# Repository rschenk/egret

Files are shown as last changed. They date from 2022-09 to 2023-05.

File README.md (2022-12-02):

# Egret

A 36 key Choc-spaced monoblock keyboard that's wireless compatible, hot swappable, gasket mounted, and very thin. Inspired by the [chocV](https://github.com/brickbots/chocV) and [Horizon](https://github.com/skarrmann/horizon/).

The Egret's bottom plate has cutouts for the hotswap sockets, essentially the thinnest board possible with hotswap sockets. Silicone gaskets sandwiching both sides of the PCB dampen sounds and vibrations. The entire bottom is covered with rubber sheet so you can use it right on your laptop keys if you're so inclined!

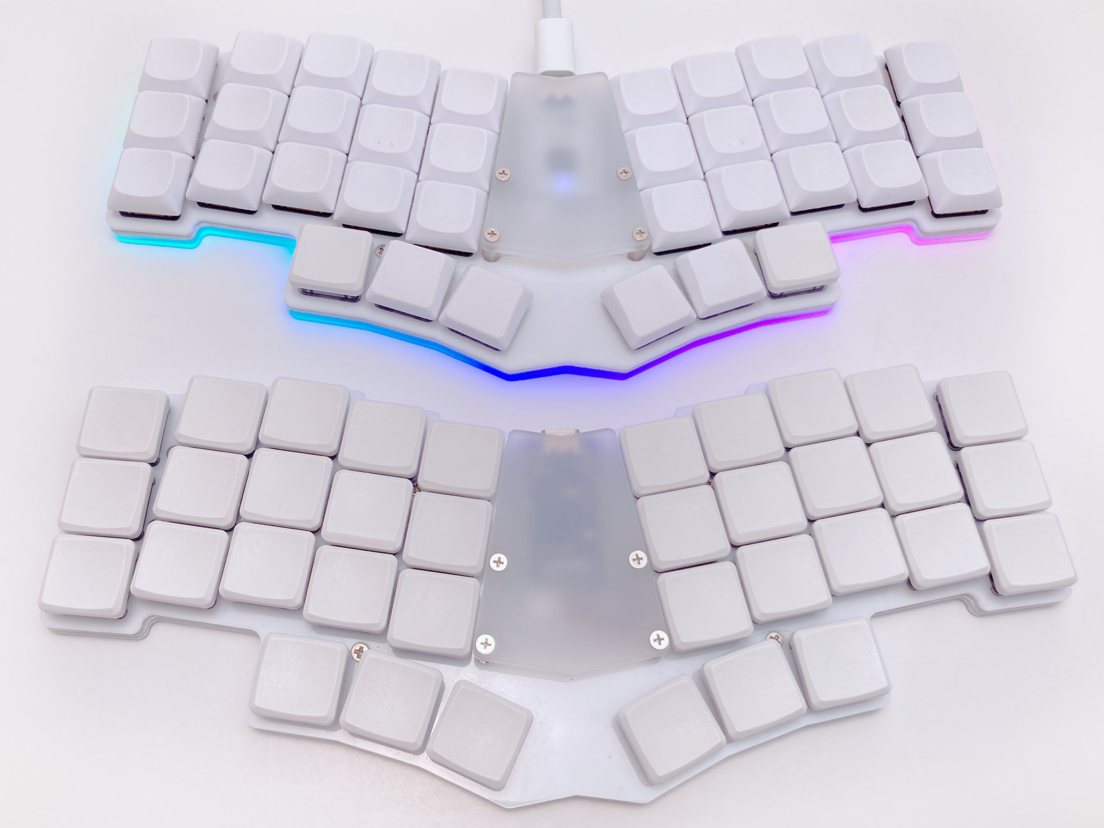
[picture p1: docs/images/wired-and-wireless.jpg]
wired-and-wireless


## Features

* Choc hotswap sockets with Choc spacing
* Gasket mounted
* On/off slider switch and JST plug for battery power
* Totally flat bottom, so you can put it right on top of your laptop keyboard and Miyoku on the go
* Optional LED underglow for wired mode, if underglow is your thing. It's very much my thing
* Two bottom plate options: lowpro mode for the thinnest board physically possible, or glowpro mode for epic underglow at the expense of a couple mm of thickess.

## Wicked Thin and Flat

The bottom plate is cut out to accomodate the hotswap sockets, making it about as thin as is physically possible to make a hotswap board. The entire bottom is intended to be covered with rubber, sililicone, EVA, etc, so you can put it down on right over your laptop's keys. Yes this actually works and is useable! 

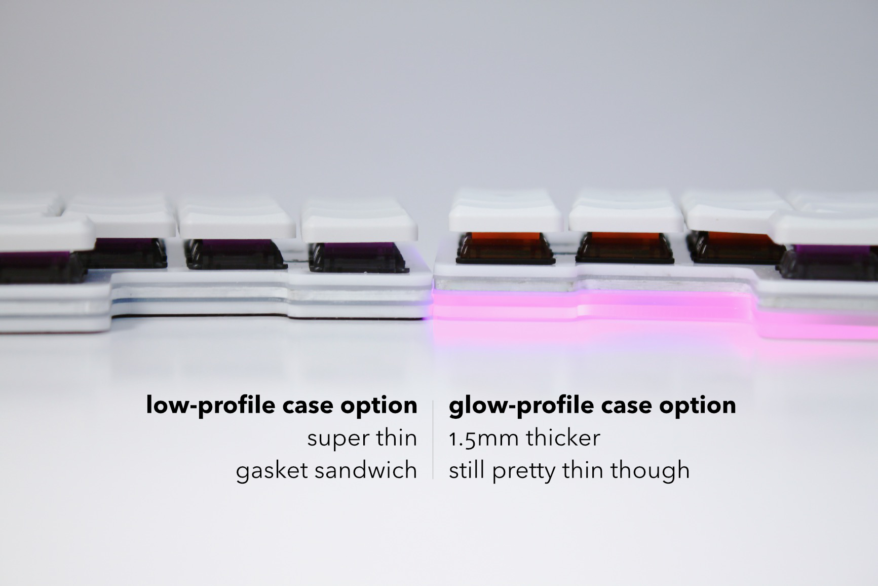
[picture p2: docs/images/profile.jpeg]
profile


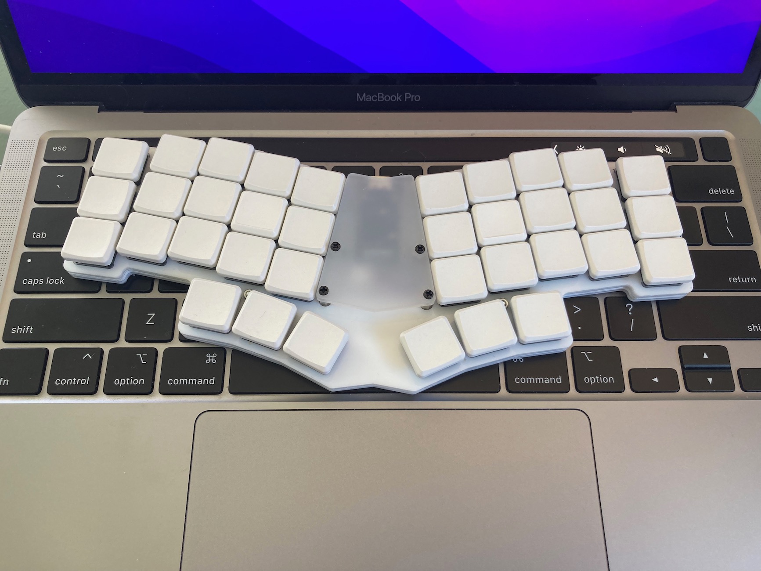
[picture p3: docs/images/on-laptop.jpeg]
on-laptop


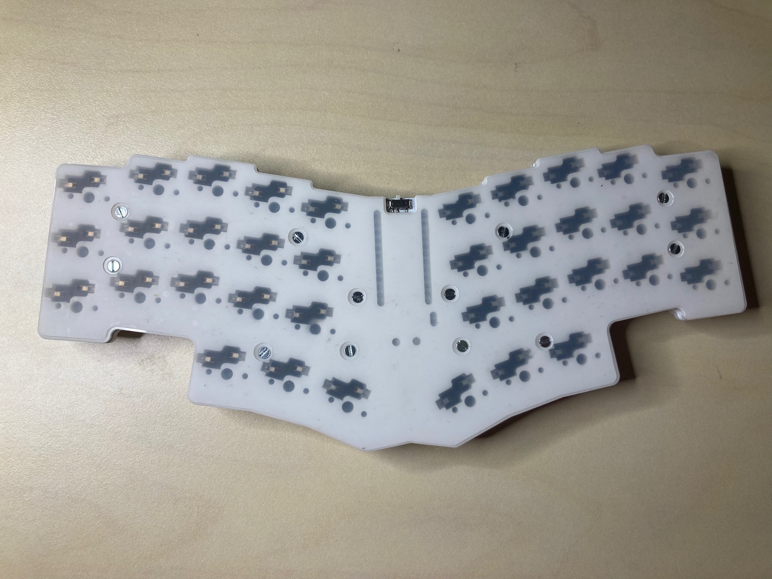
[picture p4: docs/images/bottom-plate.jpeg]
bottom-plate


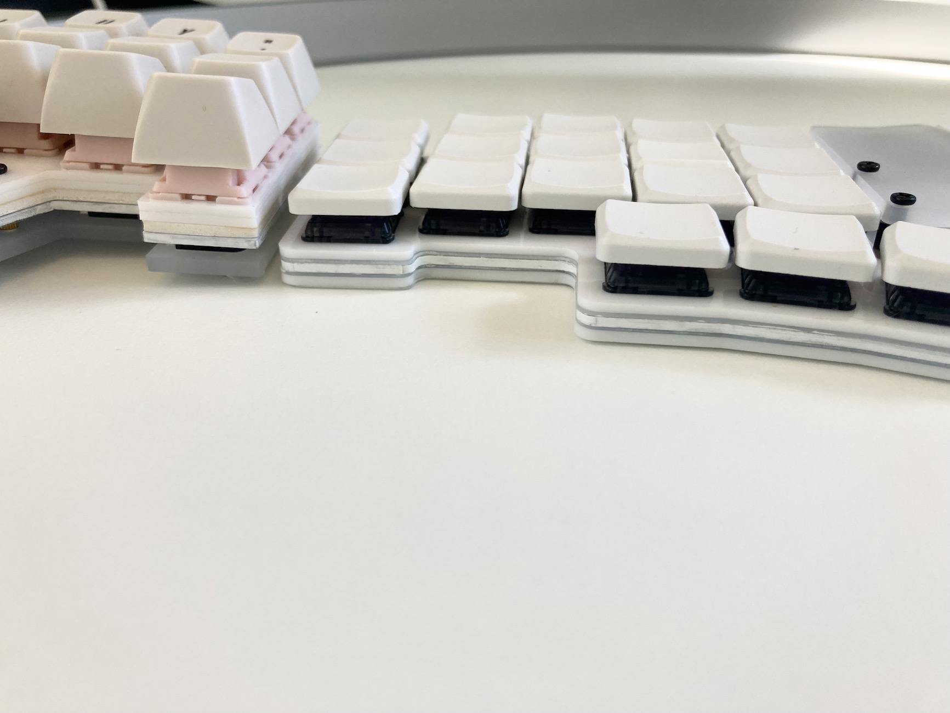
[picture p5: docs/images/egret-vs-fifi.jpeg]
egret-vs-fifi


## Build Guide

There are two ways to build it, with LED underglow (glow-profile case) and without (low profile case). The LED version requires a different bottom plate which is 1.5mm taller than the low-profile version, but everything else is the same between them—same PCB, top plate, gaskets, etc. _Either_ version can be used with bluetooth! Obviously running the LEDs will drain your battery much faster, but it's easy to have  the best of both worlds by configuring ZMK to automatically enable LEDs when plugged into USB and disable them when on battery power.

* Build guide for [low profile version](./docs/rev1/build_guide_lowpro_rev1.md) (no LEDs)
* Build guide for [glow profile version](./docs/rev1/build_guide_glowpro_rev1.md) (with LED underglow)

## Firmware

### QMK

Egret is not in the main QMK repo yet (or probably ever) but it's easy to add to your local.
Assuming you already have QMK set up on your computer, copy the contents of `./firmware/qmk` to `qmk_firmware/keyboards/egret`. There is a very minimal basic keymap for you to start with.

```sh
cp -R ./firmware/qmk /path/to/qmk_firmware/keyboards/egret
cd !$
cp -R keymaps/default keymaps/your-github-username
```

### ZMK

Egret is not in the main ZMK repo but it's easy to add. Assuming you already have a zmk-config setp already, copy the contents of `./firmware/zmk` to `zmk-config/config/boards/shields/egret`, then make the usual setup. There is a basic minimal keymap for you to start with.

```sh
cp -R ./firmware/zmk /path/to/zmk-config/config/boards/shields/egret
cd /path/to/zmk-config/config
cp boards/shields/egret/egret.keymap .
touch egret.conf
```

## Tweak Your Own With Ergogen

This board is generated with the amazing ergogen tool, then post-processed with KiCad and vector graphics drawing tools. I used several custom footrpints to pull off the "horizon construction" on the bottom plate. Since ergogen does not currently support adding footprints at runtime, I Dockerized it and copied my footprints into the image. The Dockerfile lives in `ergogen/container` and can be run with a little wrapper script I wrote in `ergogen/bin/ergogen`. 

To generate the board (which you should not need to unless you want to change something):

```shell
$ cd ergogen
$ bin/ergogen egret.yml
```

If you decide to edit a footprint, you'll need to remove the image and rebuild it.
```shell
# Only if you modify a footprint, rebuild the image like so:
$ docker image rm -f ergogen-egret && bin/ergogen egret.yml
```

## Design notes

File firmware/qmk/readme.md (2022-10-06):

# egret

egret

*A short description of the keyboard/project*

* Keyboard Maintainer: [Ryan Schenk](https://github.com/rschenk)
* Hardware Supported: *The PCBs, controllers supported*
* Hardware Availability: *Links to where you can find this hardware*

Make example for this keyboard (after setting up your build environment):

    make egret:default

Flashing example for this keyboard:

    make egret:default:flash

See the [build environment setup](https://docs.qmk.fm/#/getting_started_build_tools) and the [make instructions](https://docs.qmk.fm/#/getting_started_make_guide) for more information. Brand new to QMK? Start with our [Complete Newbs Guide](https://docs.qmk.fm/#/newbs).

## Bootloader

Enter the bootloader in 3 ways:

* **Bootmagic reset**: Hold down the key at (0,0) in the matrix (usually the top left key or Escape) and plug in the keyboard
* **Physical reset button**: Briefly press the button on the back of the PCB - some may have pads you must short instead
* **Keycode in layout**: Press the key mapped to `QK_BOOT` if it is available

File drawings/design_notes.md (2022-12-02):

PEM M2 fastener hole should be 0.118" (3.00mm) in the drawing to be a perfect fit after lasering.

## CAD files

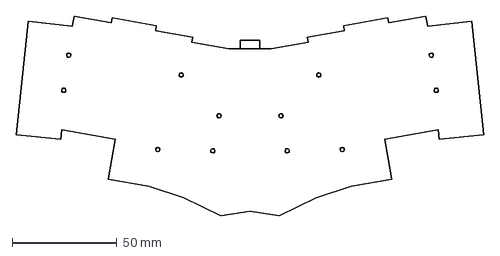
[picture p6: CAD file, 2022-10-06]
ergogen/output/outlines/bottom_plate_glowpro.dxf
223.7 x 95.4 mm

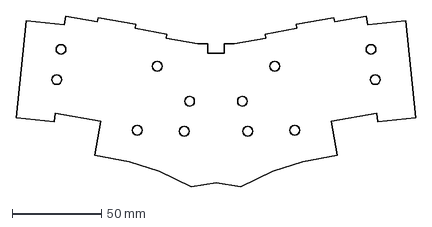
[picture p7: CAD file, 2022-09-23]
ergogen/output/outlines/bottom_grip.dxf
223.7 x 95.4 mm

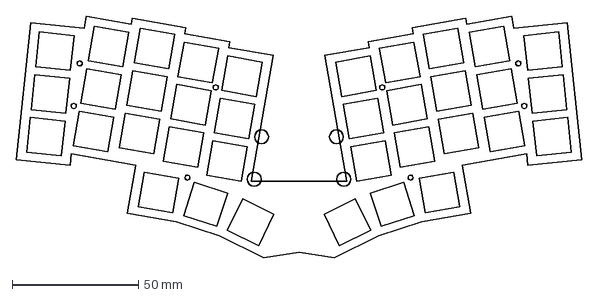
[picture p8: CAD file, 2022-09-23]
ergogen/output/outlines/top_plate.dxf
223.7 x 95.4 mm

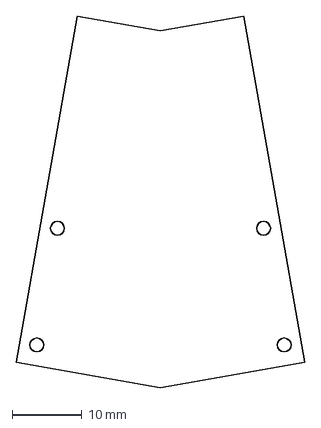
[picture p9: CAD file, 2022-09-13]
ergogen/output/outlines/mcu_cover.dxf
41.5 x 53.4 mm

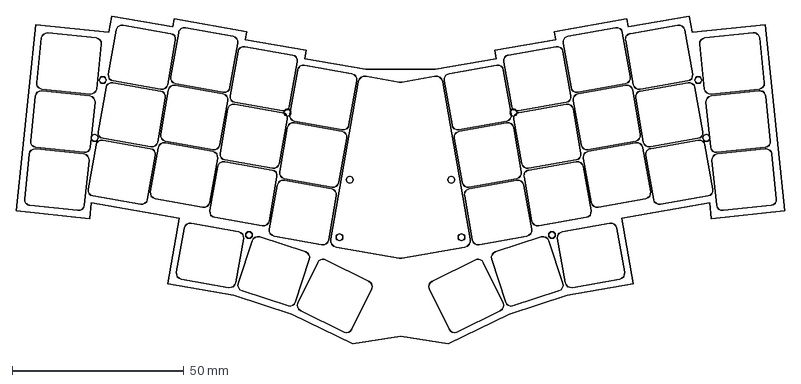
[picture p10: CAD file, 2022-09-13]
ergogen/output/outlines/test.dxf
223.7 x 95.4 mm

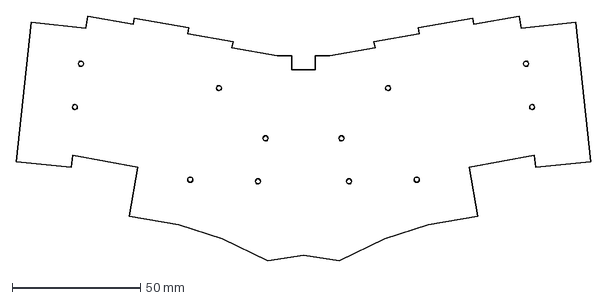
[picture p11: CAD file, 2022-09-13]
ergogen/output/outlines/bottom_plate_lowpro.dxf
223.7 x 95.4 mm

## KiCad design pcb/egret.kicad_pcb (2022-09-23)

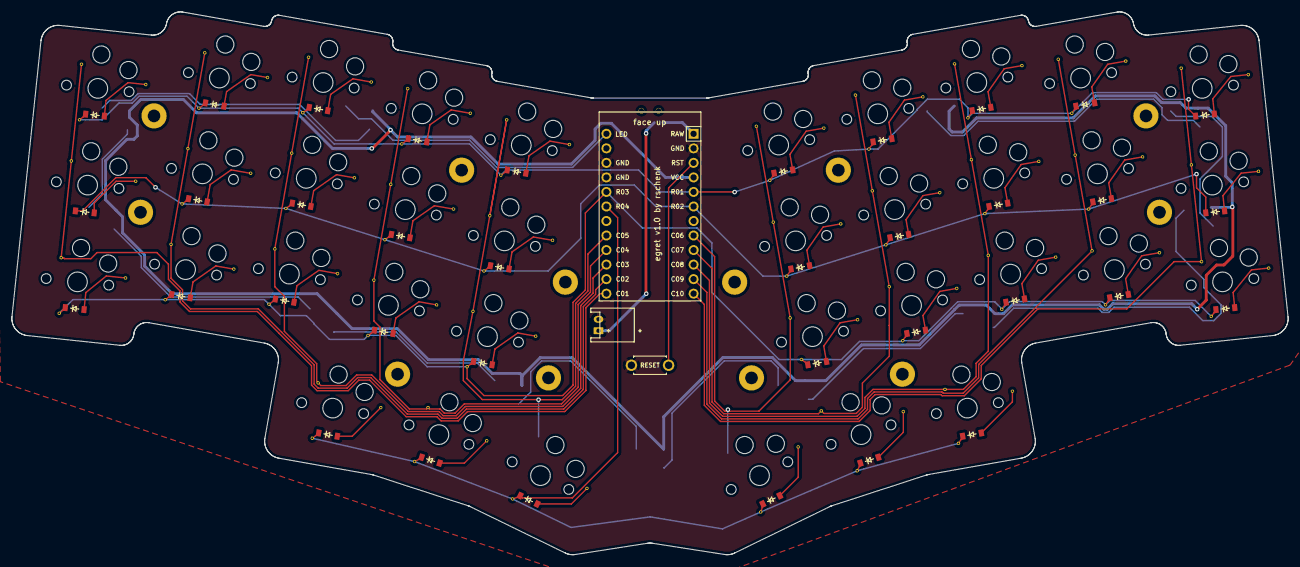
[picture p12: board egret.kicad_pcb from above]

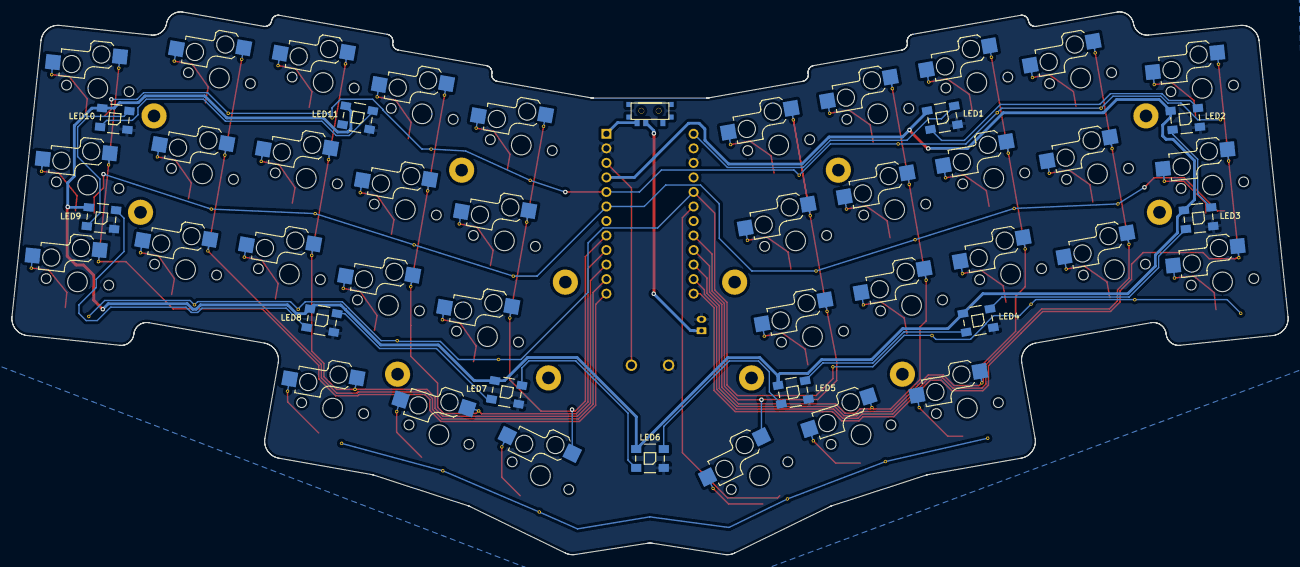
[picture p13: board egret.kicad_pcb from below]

Board: 2 copper layers, 223.1 x 94.9 mm, 100 parts (11 on the bottom side), 66 nets.

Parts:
B1: ResetSW_1side
D1, D2, D3, D4, D5, D6, D7, D8, D9, D10, D11, D12, D13, D14, D15, D16, D17, D18, D19, D20, D21, D22, D23, D24, D25, D26, D27, D28, D29, D30, D31, D32, D33, D34, D35, D36: ComboDiode
JST1: JST_PH_S2B-PH-K_02x2.00mm_Angled
LED1, LED2, LED3, LED4, LED5, LED6, LED7, LED8, LED9, LED10, LED11: VAL**; WS2812B
MCU1: ProMicro
PAD1: ProMicroPadCutouts
PAD2, PAD3, PAD4, PAD5, PAD6, PAD7, PAD8, PAD9, PAD10, PAD11, PAD12, PAD13: MountingHole_2.2mm_M2_Pad
S1, S2, S3, S4, S5, S6, S7, S8, S9, S10, S11, S12, S13, S14, S15, S16, S17, S18, S19, S20, S21, S22, S23, S24, S25, S26, S27, S28, S29, S30, S31, S32, S33, S34, S35, S36: PG1350
T1: SPDT_C128955

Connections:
BAT_POS: JST1.1, T1.2
GND: B1.2, JST1.2, LED1.3, LED2.3, LED3.3, LED4.3, LED5.3, LED6.3, LED7.3, LED8.3, LED9.3, LED10.3, LED11.3, MCU1.2, MCU1.15, MCU1.16
L2: LED1.2, LED2.4
L3: LED2.2, LED3.4
L4: LED3.2, LED4.4
L5: LED4.2, LED5.4
L6: LED5.2, LED6.4
L7: LED6.2, LED7.4
L8: LED7.2, LED8.4
L9: LED8.2, LED9.4
L10: LED9.2, LED10.4
L11: LED10.2, LED11.4
RAW: MCU1.1, T1.3
RST: B1.1, MCU1.3
VCC: LED1.1, LED2.1, LED3.1, LED4.1, LED5.1, LED6.1, LED7.1, LED8.1, LED9.1, LED10.1, LED11.1, MCU1.4
col1: MCU1.24, S1.1, S1.3, S1.5, S2.1, S2.3, S2.5, S3.1, S3.3, S3.5
col2: MCU1.23, S4.1, S4.3, S4.5, S5.1, S5.3, S5.5, S6.1, S6.3, S6.5
col3: MCU1.22, S7.1, S7.3, S7.5, S8.1, S8.3, S8.5, S9.1, S9.3, S9.5, S16.1, S16.3, S16.5
col4: MCU1.21, S10.1, S10.3, S10.5, S11.1, S11.3, S11.5, S12.1, S12.3, S12.5, S17.1, S17.3, S17.5
col5: MCU1.20, S13.1, S13.3, S13.5, S14.1, S14.3, S14.5, S15.1, S15.3, S15.5, S18.1
col6: MCU1.8, S31.1, S31.3, S31.5, S32.1, S32.3, S32.5, S33.1, S33.3, S33.5, S36.1
col7: MCU1.9, S28.1, S28.3, S28.5, S29.1, S29.3, S29.5, S30.1, S30.3, S30.5, S35.1, S35.3, S35.5
col8: MCU1.10, S25.1, S25.3, S25.5, S26.1, S26.3, S26.5, S27.1, S27.3, S27.5, S34.1, S34.3, S34.5
col9: MCU1.11, S22.1, S22.3, S22.5, S23.1, S23.3, S23.5, S24.1, S24.3, S24.5
col10: MCU1.12, S19.1, S19.3, S19.5, S20.1, S20.3, S20.5, S21.1, S21.3, S21.5
home_thumb: D17.2, S17.2, S17.4, S17.6
index_bottom: D10.2, S10.2, S10.4, S10.6
index_home: D11.2, S11.2, S11.4, S11.6
index_top: D12.2, S12.2, S12.4, S12.6
inner_bottom: D13.2, S13.2, S13.4, S13.6
inner_home: D14.2, S14.2, S14.4, S14.6
inner_top: D15.2, S15.2, S15.4, S15.6
led: LED1.4, MCU1.13
middle_bottom: D7.2, S7.2, S7.4, S7.6
middle_home: D8.2, S8.2, S8.4, S8.6
middle_top: D9.2, S9.2, S9.4, S9.6
mirror_home_thumb: D35.2, S35.2, S35.4, S35.6
mirror_index_bottom: D28.2, S28.2, S28.4, S28.6
mirror_index_home: D29.2, S29.2, S29.4, S29.6
mirror_index_top: D30.2, S30.2, S30.4, S30.6
mirror_inner_bottom: D31.2, S31.2, S31.4, S31.6
mirror_inner_home: D32.2, S32.2, S32.4, S32.6
mirror_inner_top: D33.2, S33.2, S33.4, S33.6
mirror_middle_bottom: D25.2, S25.2, S25.4, S25.6
mirror_middle_home: D26.2, S26.2, S26.4, S26.6
mirror_middle_top: D27.2, S27.2, S27.4, S27.6
mirror_pinky_bottom: D19.2, S19.2, S19.4, S19.6
mirror_pinky_home: D20.2, S20.2, S20.4, S20.6
mirror_pinky_top: D21.2, S21.2, S21.4, S21.6
mirror_reachy_thumb: D36.2, S36.2, S36.4, S36.6
mirror_ring_bottom: D22.2, S22.2, S22.4, S22.6
mirror_ring_home: D23.2, S23.2, S23.4, S23.6
mirror_ring_top: D24.2, S24.2, S24.4, S24.6
mirror_tucky_thumb: D34.2, S34.2, S34.4, S34.6
pinky_bottom: D1.2, S1.2, S1.4, S1.6
pinky_home: D2.2, S2.2, S2.4, S2.6
pinky_top: D3.2, S3.2, S3.4, S3.6
reachy_thumb: D18.2, S18.2, S18.4, S18.6
ring_bottom: D4.2, S4.2, S4.4, S4.6
ring_home: D5.2, S5.2, S5.4, S5.6
ring_top: D6.2, S6.2, S6.4, S6.6
row1: D3.1, D3.3, D3.4, D6.1, D6.3, D6.4, D9.1, D9.3, D9.4, D12.1, D12.3, D12.4, D15.1, D15.3, D15.4, D21.1, D24.1, D24.3, D24.4, D27.1, D27.3, D27.4, D30.1, D30.3, D30.4, D33.1, D33.3, D33.4, MCU1.5
row2: D2.1, D5.1, D5.3, D5.4, D8.1, D8.3, D8.4, D11.1, D11.3, D11.4, D14.1, D14.3, D14.4, D20.1, D23.1, D23.3, D23.4, D26.1, D26.3, D26.4, D29.1, D29.3, D29.4, D32.1, D32.3, D32.4, MCU1.6
row3: D1.1, D1.3, D1.4, D4.1, D4.3, D4.4, D7.1, D7.3, D7.4, D10.1, D10.3, D10.4, D13.1, D13.3, D13.4, D19.1, D19.3, D19.4, D22.1, D22.3, D22.4, D25.1, D25.3, D25.4, D28.1, D28.3, D28.4, D31.1, D31.3, D31.4, MCU1.17
row4: D16.1, D16.3, D16.4, D17.1, D17.3, D17.4, D18.1, D18.3, D18.4, D34.1, D34.3, D34.4, D35.1, D35.3, D35.4, D36.1, D36.3, D36.4, MCU1.18
tucky_thumb: D16.2, S16.2, S16.4, S16.6

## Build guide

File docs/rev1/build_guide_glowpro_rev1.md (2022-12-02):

# Egret Glow-Profile Build Guide

## Required parts

### Parts for the case (laser cut)

The difference between the low-profile and the glow-profile model, aside from the LEDs, is the bottom plate(s). The top plate, top gasket, pcb, and bottom grip are the same between the two models. The lowpro model uses the lowpro bottom gasket, and the lowpro bottom plate.

The top and bottom plates are made from 1.5mm (1/16") acrylic and the top gasket is made from 0.7mm (1/32") silicone.

The bottom grip can be made from any sticky-back padded sheet, including silicone, epdm rubber, or eva foam. The bottom grip is somewhat optional. If you want to use the Egret only on your desk, then you can skip the bottom grip and just use the little silicone bumpers. However, for the lowest profile and the ability to use the keyboard directly on top of your laptop, I recommend the bottom grip layer.

Please note that *once you put LEDs on the PCB you are stuck with the glow-profile case,* the low-profile case won't fit.

### A note on hardware

There are two ways to build the case, either using wafer head screws or countersunk flat heads. The latter requires you to have a drill press and countersink bit, so if you don't have those, stop reading and go with the wafer heads.

Going with countersunk screws has the advantage of being cheaper, more readily available, and totally flat. In testing this board with the prototype LDSA keycaps, the wafer heads did interfere with the keycaps *ever so slightly,* which I and others reported in our feedback. It's not known at this time whether the designer of those keycaps will make the skirt slightly higher to clear wafer heads or not... so if that concerns you then countersink.

| Part | Quantity | Comments |
| --- | --- | --- |
| Egret top plate | 1 | 1.5mm (1/16") acrylic |
| Egret lowpro bottom plate inner | 1 | 1.5mm (1/16") frosted acrylic. Make sure you use the correct file. I like this "satin ice" acrylic from [Canal Plastic](https://www.canalplastic.com/collections/acrylic-sheets/products/0d010-df-frosted-satin-ice-acrylic-sheet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) |
| Egret lowpro bottom plate outer | 1 | 1.5mm (1/16") frosted acrylic, same as the inner layer. |
| Egret cover plate | 1 | 3mm or 1.5mm acrylic. If you go with 1.5, you'll probably want 4mm instead of the 6mm pan head screws below |
| Egret top gasket | 1 | 0.7mm silicone [Amazon](https://www.amazon.com/gp/product/B088LKLSTG/) (what I used), or [McMaster](https://www.mcmaster.com/86465K21) (would probably work) |
| Egret bottom grip | 1 | Many options, including: 1mm clear sticky-backed silicone [Amazon](https://www.amazon.com/dp/B01N311P9D) [McMaster](https://www.mcmaster.com/86465K34/), 1/64" black EPDM rubber [McMaster](https://www.mcmaster.com/8610K102), or 1mm EVA foam [Amazon](https://www.amazon.com/dp/B07T5L7756/). Note that all of these are laser-safe, neoprene rubber is not. For maximum glow I would choose clear silicone or white EVA. |
| 6mm M2 wafer head screws | 12 | **Option 1 of 2.** Use this option if you do not have a drill press. [Metric Screws US](https://www.metricscrews.us/index.php?main_page=index&cPath=155_156_162&zenid=ehth7nvdt09u23fh2sd1oqksk7) has singles |
| 6mm M2 flat head screws | 12 | **Option 2 of 2.** Use this option if you have a drill press and countersink bit, to get the flattest possible design and because they're cheaper and easier to get. [McMaster](https://www.mcmaster.com/screws/system-of-measurement~metric/thread-size~m2/length~6-mm/flat-head-screws-4/material~stainless-steel/) |
| 8mm M2 wafer head screws | 4 | **Option 1 of 2.** Use this option if you do not have a drill press. [Metric Screws US](https://www.metricscrews.us/index.php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) has singles |
| 8mm M2 flat head screws | 4 | **Option 2 of 2.** Use this option if you have a drill press and countersink bit, to get the flattest possible design and because they're cheaper and easier to get. [McMaster](https://www.mcmaster.com/screws/system-of-measurement~metric/thread-size~m2/length~8-mm/flat-head-screws-4/material~stainless-steel/) |
| 3mm M2 thraded inserts | 8 | PEM MSO4-M2-3 [McMaster](https://www.mcmaster.com/92985A818/) |
| 8mm M2 standoffs | 4 | [DigiKey](https://www.digikey.com/en/products/detail/würth-elektronik/970080244/9488540) or anywhere |

### Parts for the circuit board

| Part | Quantity | Comments |
| --- | --- | --- |
| Egret PCB | 1 | |
| Pro-micro footprint MCU | 1 | I used a [Nice!Nano](https://nicekeyboards.com/nice-nano/) on the wireless build and a [Bit-C](https://nullbits.co/bit-c/) on the wired |
| 12-pin socket headers | 2 | Optional. Mill-Max 310 series for wireless ([DigiKey](https://www.digikey.com/en/products/detail/mill-max-manufacturing-corp/310-43-112-41-001000/1212186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)), or low profile Mill-Max 315 series for wired ([DigiKey](https://www.digikey.com/en/products/detail/mill-max-manufacturing-corp/315-43-112-41-003000/4455232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)) |
| Socket pins | 48 | Optional. Mill-Max 3320-0-00-15-00-00-03-0 [DigiKey](https://www.digikey.com/en/products/detail/mill-max-manufacturing-corp/3320-0-00-15-00-00-03-0/4147392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) or diode legs. Buy like 5 extras, you'll lose them. |
| LEDs | 11 | WS2812B 5050, aka Neopixels. There are several compatble chips, just makes sure you get the 5050 package. [DigiKey](https://www.digikey.com/en/products/detail/sparkfun-electronics/COM-16347/11630204) |
| Kailh Choc hot swap sockets | 36 | [DigiKey](https://www.digikey.com/en/products/detail/adafruit-industries-llc/5118/14671678) |
| Diodes | 36 | 1N4148W SOD123 [DigiKey](https://www.digikey.com/en/products/detail/smc-diode-solutions/1N4148W/6022450) |
| Tactile reset switch | 1 | 6.0 x 3.5mm, same one used on Corne. TL1107AF180WQ [DigiKey](https://www.digikey.com/en/products/detail/e-switch/TL1107AF180WQ/378977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) are black, 1489 [DigiKey](https://www.digikey.com/en/products/detail/adafruit-industries-llc/1489/10670004) are white |
| Slider switch | 1 | Required for wireless, not needed for wired. MSK-12C02, or pretty sure CUS-12TB ([Digikey](https://www.digikey.com/en/products/detail/nidec-copal-electronics/CUS-12TB/1124222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)) will work but I haven't tried it. |
| JST PH2.0 battery jack | 1 | Required for wireless, not needed for wired. S2B-PH-K-S(LF)(SN) [DigiKey](https://www.digikey.com/en/products/detail/jst-sales-america-inc/S2B-PH-K-S-LF-SN/926626) |

## PCB Assembly

I like to paint the edges of my PCBs with paint marker to match whatever case I'm putting it in, so consider doing that now.

Gotta start somewhere, lets do the power switch first. Put a small dot of solder on one of the pads on the board, place the reset switch, then heat that dot to tack it in place. Now with the switch tacked in place you can do the rest of the pads.

At this point, you can choose to etiher solder the LEDs on one-at-a-time and test them as you go, or you can yolo them all at once and test them later. If you choose to do one-at-a-time then you'll need to solder on the MCU now and flash it. I did this once but it was really annoying, so subsequent builds I have just soldered them all at once. I put the LED numbers on the silk screen for easy debugging. 

Next solder on all the LEDs. There is a great [video of how to solder these LEDs](https://twitter.com/GTIPS_SH/status/1204244088867807234?s=20) courtesy of Reviung. Please pay attention to the silk screen on the board, there is a little notch cut out of the component, that will need to align with the corresponding notch on the silk screen. I like about 300ºC on the soldering iron. 

Next solder on all the hotswap sockets in a similar fashion.

Flip the board over and solder on all the diodes. Mind the direction.

Finally, solder on the JST connector, reset button, and headers for the MCU board.

## Case Assembly

If using counter sunk screws, then drill counter sinks on all the holes on the top plate. Also counter sink the four center holes on the bottom plate, and the four holes on the MCU cover plate. To counter sink acrylic, I like the five-flute bits, use a low speed and light pressure and it will cut like butter. Skip this step if using wafer heads.

Press the eight threaded inserts into the bottom plate with the flange on the bottom side.

Next apply the bottom grip to the bottom plate. The best way to do this is with a spray bottle of water with a small drop of soap. Spray a good mist of water onto the bottom plate, peel the backing paper off the grip adhesive, spray a good mist of water on the adhesive, then float the grip into place. More water is better than less. Once it's lined up, lightly squeegee the water out with an old credit card or similar. This technique is how people who do vinyl graphics get a perfect placement every time. Obviously do this before you put the bottom plate onto the PCB.

While the above is drying, install the switches and MCU. I like to do this now with the PCB sitting on the table, so that the force of setting the switche home is directed into the tabletop instaed of the solder holding the hotswap sockets on. Put the assembled PCB onto a table, put on the top gasket and top plate. You can slide a few screws into the holes to align all the layers. Then start installing switches. I like to install some on the corners and thumb cluster to help align everything, then do them all.

Install the MCU and battery. Please be careful with the battery polarity, it is marked on the PCB with a small  `+`, and is the so-called standard (according to Adafruit) of the positive (red) wire on the left. 

Once the bottom plate is completely dry from the above, place the inner bottom plate (be careful, it only goes on one way), and the outer bottom plate. Note that unlike the low-profile case, there is no bottom gasket between the pcb and the plate. Install the screws down from the top plate, then the ones for the MCU cover and standoffs. Install the cover and you're good to go.

## Battery and Power

The battery connector polarity is marked on the PCB. The positive (red) wire should be on the left side of the connector.

The power slider switch goes to the right-hand side for on, left-hand side for off when viewed from the keys side of the board.

And yes, you totally can run the glow-profile model with a battery and a Nice Nano, but be aware that running the LEDs off battery power will drain your battery extremely rapidly. What I do is only turn on the LEDs when I am plugged into USB. Use ZMK's [external power control](https://zmk.dev/docs/behaviors/power#external-power-control-command-defines) to turn the LEDs on and off by adding  `&ext_power EP_TOG` to your keymap.

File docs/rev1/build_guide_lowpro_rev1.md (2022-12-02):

# Egret Low-Profile Build Guide

## Required parts

### Parts for the case (laser cut)

The difference between the low-profile and the glow-profile model, aside from the LEDs, is the bottom plate(s). The top plate, top gasket, pcb, and bottom grip are the same between the two models. The lowpro model uses the lowpro bottom gasket, and the lowpro bottom plate.

The top and bottom plate are made from 1.5mm (1/16") acrylic and the top and bottom gasket are made from 0.7mm (1/32") silicone.

The bottom grip can be made from any sticky-back padded sheet, including silicone, epdm rubber, or eva foam. The bottom grip is somewhat optional. If you want to use the Egret only on your desk, then you can skip the bottom grip and just use the little silicone bumpers. However, for the lowest profile and the ability to use the keyboard directly on top of your laptop, I recommend the bottom grip layer.

Please note that *once you put LEDs on the PCB you are stuck with the glow-profile case,* the low-profile case won't fit.

### A note on hardware

There are two ways to build the case, either using wafer head screws or countersunk flat heads. The latter requires you to have a drill press and countersink bit, so if you don't have those, stop reading and go with the wafer heads.

Going with countersunk screws has the advantage of being cheaper, more readily available, and totally flat. In testing this board with the prototype LDSA keycaps, the wafer heads did interfere with the keycaps *ever so slightly,* which I and others reported in our feedback. It's not known at this time whether the designer of those keycaps will make the skirt slightly higher to clear wafer heads or not... so if that concerns you then countersink.

| Part | Quantity | Comments |
| --- | --- | --- |
| Egret top plate | 1 | 1.5mm (1/16") acrylic |
| Egret lowpro bottom plate | 1 | 1.5mm (1/16") acrylic. Make sure you use the corret file. |
| Egret cover plate | 1 | 3mm or 1.5mm acrylic. If you go with 1.5, you'll probably want 4mm instead of the 6mm pan head screws below |
| Egret top gasket | 1 | 0.7mm silicone [Amazon](https://www.amazon.com/gp/product/B088LKLSTG/) (what I used), or [McMaster](https://www.mcmaster.com/86465K21) (would probably work) |
| Egret bottom gasket | 1 | 0.7mm silicone |
| Egret bottom grip | 1 | Many options, including: 1mm clear sticky-backed silicone [Amazon](https://www.amazon.com/dp/B01N311P9D) [McMaster](https://www.mcmaster.com/86465K34/), 1/64" black EPDM rubber [McMaster](https://www.mcmaster.com/8610K102), or 1mm EVA foam [Amazon](https://www.amazon.com/dp/B07T5L7756/). Note that all of these are laser-safe, neoprene rubber is not. |
| 6mm M2 wafer head screws  | 16 | **Option 1 of 2.** Use this option if you do not have a drill press. [Metric Screws US](https://www.metricscrews.us/index.php?main_page=index&cPath=155_156_162&zenid=ehth7nvdt09u23fh2sd1oqksk7) has singles |
| 6mm M2 flat head screws | 16 | **Option 2 of 2.** Use this option if you have a drill press and countersink bit, to get the flattest possible design and because they're cheaper and easier to get. [McMaster](https://www.mcmaster.com/screws/system-of-measurement~metric/thread-size~m2/length~6-mm/flat-head-screws-4/material~stainless-steel/) |
| 2mm M2 thraded inserts | 8 | PEM MSO4-M2-2 [McMaster](https://www.mcmaster.com/92985A817//) |
| 8mm M2 standoffs | 4 | [DigiKey](https://www.digikey.com/en/products/detail/würth-elektronik/970080244/9488540) or anywhere |

### Parts for the circuit board

| Part | Quantity | Comments |
| --- | --- | --- |
| Egret PCB | 1 | |
| Pro-micro footprint MCU | 1 | I used a [Nice!Nano](https://nicekeyboards.com/nice-nano/) on the wireless build and a [Bit-C](https://nullbits.co/bit-c/) on the wired |
| 12-pin socket headers | 2 | Optional. Mill-Max 310 series for wireless ([DigiKey](https://www.digikey.com/en/products/detail/mill-max-manufacturing-corp/310-43-112-41-001000/1212186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)), or low profile Mill-Max 315 series for wired ([DigiKey](https://www.digikey.com/en/products/detail/mill-max-manufacturing-corp/315-43-112-41-003000/4455232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)) |
| Socket pins | 48 | Optional. Mill-Max 3320-0-00-15-00-00-03-0 [DigiKey](https://www.digikey.com/en/products/detail/mill-max-manufacturing-corp/3320-0-00-15-00-00-03-0/4147392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) or diode legs. Buy like 5 extras, you'll lose them. |
| Kailh Choc hot swap sockets | 36 | [DigiKey](https://www.digikey.com/en/products/detail/adafruit-industries-llc/5118/14671678) |
| Diodes | 36 | 1N4148W SOD123 [DigiKey](https://www.digikey.com/en/products/detail/smc-diode-solutions/1N4148W/6022450) |
| Tactile reset switch | 1 | 6.0 x 3.5mm, same one used on Corne. TL1107AF180WQ [DigiKey](https://www.digikey.com/en/products/detail/e-switch/TL1107AF180WQ/378977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) are black, 1489 [DigiKey](https://www.digikey.com/en/products/detail/adafruit-industries-llc/1489/10670004) are white |
| Slider switch | 1 | Required for wireless, not needed for wired. MSK-12C02, or pretty sure CUS-12TB ([Digikey](https://www.digikey.com/en/products/detail/nidec-copal-electronics/CUS-12TB/1124222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)) will work but I haven't tried it. |
| JST PH2.0 battery jack | 1 | Required for wireless, not needed for wired. S2B-PH-K-S(LF)(SN) [DigiKey](https://www.digikey.com/en/products/detail/jst-sales-america-inc/S2B-PH-K-S-LF-SN/926626) |

## PCB Assembly

I like to paint the edges of my PCBs with paint marker to match whatever case I'm putting it in, so consider doing that now.

Gotta start somewhere, lets do the power switch first. Put a small dot of solder on one of the pads on the board, place the reset switch, then heat that dot to tack it in place. Now with the switch tacked in place you can do the rest of the pads.

Next solder on all the hotswap sockets in a similar fashion.

Flip the board over and solder on all the diodes. Mind the direction.

Finally, solder on the JST connector, reset button, and headers for the MCU board.

## Case Assembly

Test fit the bottom plate onto the PCB. Due to the hotswap sockets not being symmetrical, there is a right and a wrong way. The tolerances are somewhat tight, so check for any sloppy, blobby solder joints and make sure everything fits. Put a piece of masking tape, or dot with marker on the bottom side of the plate for the next two steps.

If using counter sunk screws, then drill counter sinks on all the holes on the top plate. Also counter sink the four center holes on the bottom plate, and the four holes on the MCU cover plate. To counter sink acrylic, I like the five-flute bits, use a low speed and light pressure and it will cut like butter. Skip this step if using wafer heads.

Press the eight threaded inserts into the bottom plate with the flange on the bottom side.

Next apply the bottom grip to the bottom plate. The best way to do this is with a spray bottle of water with a small drop of soap. Spray a good mist of water onto the bottom plate, peel the backing paper off the grip adhesive, spray a good mist of water on the adhesive, then float the grip into place. More water is better than less. Once it's lined up, lightly squeegee the water out with an old credit card or similar. This technique is how people who do vinyl graphics get a perfect placement every time. Obviously do this before you put the bottom plate onto the PCB.

While the above is drying, install the switches and MCU. I like to do this now with the PCB sitting on the table, so that the force of setting the switche home is directed into the tabletop instaed of the solder holding the hotswap sockets on. Put the assembled PCB onto a table, put on the top gasket and top plate. You can slide a few screws into the holes to align all the layers. Then start installing switches. I like to install some on the corners and thumb cluster to help align everything, then do them all.

Install the MCU and battery. Please be careful with the battery polarity, it is marked on the PCB with a small  `+`, and is the so-called standard (according to Adafruit) of the positive (red) wire on the left. 

Once the bottom plate is completely dry from the above, place on the bottom gasket and bottom plate. Install the screws down from the top plate, then the ones for the MCU cover and standoffs. Install the cover and you're good to go.

## Battery and Power

The battery connector polarity is marked on the PCB. The positive (red) wire should be on the left side of the connector.

The power slider switch goes to the right-hand side for on, left-hand side for off when viewed from the keys side of the board.

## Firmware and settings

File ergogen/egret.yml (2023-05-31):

units:
  capw: 17.5        # Keycap width
  caph: 16.5        # Keycap height
  kx: 1cx           # Key spacing horizontal
  ky: 1cy           # Key spacing vertical
  center_spread: 45 # Distance between inner top keys *on center*
  master_angle: 10  # Degrees that the two halves are angled
  pinky_splay: -4   # Degrees of splay between pinky and ring
  thumb_home_splay: 8
  thumb_reachy_splay: 8
  thumb_shift_x: -24.48
  thumb_shift_y: -ky
  ring_stagger: 4.75
  middle_stagger: 2.375
  index_stagger: -2.375
  inner_stagger: -2.375

  # Outlines
  edge_border: 2 # border around the pcb, outside the keycaps' perimeter
  outer_kx: (capw + 2edge_border)
  outer_ky: (caph + 2edge_border)
  cover_hole_margin: 3
  mounting_hole_r: 1
  clearance_hole_r: 2.75
  # Y component of the outer corner of a switch, after it's been rotated by master_angle
  outer_corner_y: 8.228 # −(outer_kx/2) * sin(master_angle * pi/180) + (outer_ky/2) * cos(master_angle * pi/180)

  # Components
  promicro_w: 33
  promicro_h: 19
  promicro_shift_x: 0
  promicro_shift_y: -12
  power_switch_w: 9.3
  power_switch_h: 5.4
  reset_w: 6.0
  reset_h: 3.5
  bat_plug_w: 7.6
  bat_plug_h: 5.9

  # Laser
  kerf: 0.006 * 25.4 # Inches to mm

points:
  rotate: -master_angle
  key:
    padding: ky
    footprints:
      choc:
        type: choc
        params:
          hotswap: true
          reverse: false
          keycaps: true
          bottom_plate_cutouts: true
          hotswap_vias: true
        nets:
          from: =column_net
          to: =colrow
      diode:
        type: diode
        params:
          through_hole: false
          front: true
          back: false
          via: true
        nets:
          from: =colrow
          to: =row_net
        anchor:
          shift: [0, -4.7]
  zones.matrix:
    anchor:
      shift: [100, -100] # Center on KiCad sheet
    rotate: -pinky_splay
    columns:
      pinky:
        spread: kx
        rows:
          top.bind: [0,4,0,0]
          home.bind: [0,4,0,0]
        key:
          column_net: col1
          mirror.column_net: col10
      ring:
        rotate: pinky_splay
        origin: [-kx/2, -ky/2]
        stagger: ring_stagger
        spread: kx
        rows.bottom.bind: [0,kx,0,0]
        key:
          column_net: col2
          mirror.column_net: col9
      middle:
        stagger: middle_stagger
        spread: kx
        key:
          column_net: col3
          mirror.column_net: col8
      index:
        stagger: index_stagger
        spread: kx
        key:
          column_net: col4
          mirror.column_net: col7
      inner:
        stagger: inner_stagger
        spread: kx
        key:
          column_net: col5
          mirror.column_net: col6
    rows:
      bottom.row_net: row3
      home.row_net: row2
      top.row_net: row1

  zones.thumbfan:
    anchor:
      ref: matrix_inner_bottom
      shift: [thumb_shift_x, thumb_shift_y]
    columns:
      tucky:
        rows.thumb.bind: [10,0,0,0]
        key:
          column_net: col3
          mirror.column_net: col8
      home:
        rotate: -thumb_home_splay
        origin: [-kx/2, -ky/2]
        spread: kx
        rows.thumb.bind: [10,0,0,5]
        key:
          column_net: col4
          mirror.column_net: col7
      reachy:
        rotate: -thumb_reachy_splay
        origin: [-kx/2, -ky/2]
        spread: kx
        rows.thumb.bind: [10,0,0,4]
        key:
          column_net: col5
          mirror.column_net: col6
    rows:
      thumb.row_net: row4

  mirror:
    ref: matrix_inner_top
    distance: center_spread
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

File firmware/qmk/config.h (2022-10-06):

// Copyright 2022 Ryan Schenk (@rschenk)
// SPDX-License-Identifier: GPL-2.0-or-later

#pragma once

#define MATRIX_ROWS 4
#define MATRIX_COLS 10

#define MATRIX_ROW_PINS { F4, F5, D1, D0 }
#define MATRIX_COL_PINS { B5, B4, E6, D7, C6, F7, B1, B3, B2, B6 }

#define DIODE_DIRECTION COL2ROW

#define DEBOUNCE 5

#define RGB_DI_PIN D3

#ifdef RGBLIGHT_ENABLE
  #define RGBLED_NUM 11

  // remove
  #define RGBLIGHT_EFFECT_RAINBOW_SWIRL   // enable _only_ rainbow swirl
  #define RGBLIGHT_SLEEP                  // turn off LEDs when host sleeps
  #define RGBLIGHT_LAYERS                 // per-layer LED effects
  #define RGBLIGHT_DEFAULT_MODE RGBLIGHT_MODE_RAINBOW_SWIRL
  #define RGBLIGHT_DEFAULT_HUE 220        // purple rain
#endif

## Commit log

2022-09-13 v1.0 pcb design, gitignore
    [egret-B_Cu.gbr, egret-B_Mask.gbr, egret-B_Paste.gbr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]
2022-09-14 Subtract soldermask from silkscreen in gerbers
    [egret-B_Cu.gbr, egret-B_Mask.gbr, egret-B_Paste.gbr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]
2022-09-23 Subtract mask from silkscreens
    [egret.kicad_pcb]
2022-09-23 Bigger standoff clearance on top plate
    [bottom_grip.dxf, top_plate.dxf]
2022-10-06 Power switch cutout for glowpro bottom plate
    [bottom_plate_glowpro.dxf]
2023-07-19 Fix nice nano zmk board config
